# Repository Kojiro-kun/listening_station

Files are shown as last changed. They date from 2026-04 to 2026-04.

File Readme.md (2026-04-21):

# RF Listening Station

A high-performance radio receiver system based on the HackRF Pro, designed for stable, sensitive RF signal reception. This build combines precision clock synchronization, RF protection, and a portable form factor for reliable spectrum monitoring and analysis.

## Overview

This listening station delivers professional-grade performance through careful component selection and proper RF shielding. The core features include:

- **HackRF Pro** receiver for wideband signal reception (30 MHz - 6 GHz)
- **GPS-disciplined oscillator (GPSDO)** for frequency accuracy and stability
- **RF protection** via a limiter and attenuators for handling high-power signals
- **Battery-powered** operation for portable deployment
- **Compact mechanical design** using precision-machined discs and 3D-printed mounts

---

## Bill of Materials

### Radio Frequency Hardware

| Component | Part Number | Purpose |
|---|---|---|
| [HackRF Pro](https://greatscottgadgets.com/hackrf/pro/) | - | Wideband SDR receiver |
| [Mini-Circuits 6GHz Limiter](https://www.minicircuits.com/WebStore/dashboard.html?model=VLM-63-2W-S%2B) | VLM-63-2W-S+ | RF signal clipping & ESD protection |
| [Mini-Circuits DC to 6 GHz Attenuator](https://www.minicircuits.com/WebStore/dashboard.html?model=K1-VAT-A%2B) | K1-VAT-A+ | Input attenuation for high-power signals |
| [Double-shielded RG316D coax pigtail](https://www.ebay.com/itm/145242622653) | 10cm, SMA-M to SMA-M | Connects GPSDO to HackRF CLKIN |
| [Shielded M-F RG316 coax pigtail](https://www.amazon.com/dp/B091TH6CCJ?th=1) | 15cm, B091TH6CCJ | SMA bulkhead for the ground plane and HackRF |
| [SMA-M telescopic antenna](https://greatscottgadgets.com/ant500/) | ANT500 | Atatches to SMA bulkhead |

Also check out [Signal Stick SMA-M](https://signalstuff.com/products/st-sma-m/) antennas for easy access to HAM bands.

### Clock & Timing

| Component | Description |
|---|---|
| [Leo Bodnar LBE-1420 GPSDO](https://www.leobodnar.com/shop/index.php?main_page=product_info&products_id=393) | GPS-disciplined reference clock |
| [Leo Bodnar LBE-0006 Bracket](https://www.leobodnar.com/shop/index.php?main_page=product_info&products_id=402) | Mounting bracket for GPSDO |

### Power & USB

| Component | Specification | Purpose |
|---|---|---|
| [Bioenno Power Battery](https://www.bioennopower.com/products/12v-3ah-lifepo4-battery-pvc?_pos=2&_fid=890042680&_ss=c) | BLF-1203AB 12V 3Ah LiFePO4 | Clean DC power supply (8-10 hour runtime) |
| [DC Power Cable](https://www.amazon.com/dp/B0CW2MTHKS?th=1) | 5.5mm × 2.1mm male | Battery to hub connector |
| [StarTech USB C Hub](https://www.startech.com/en-us/usb-hubs/hb31c2a2cme) | 4-port, 10Gbps | Industrial low-EMI USB hub |
| [Digirig Shielded USB Cables](https://digirig.net/product/short-usb-a-to-usb-c-cable/) | Shielded and RF choked | High-quality USB 2.0 connectivity |

**Note:** You will need an Anderson Powerpole crimper and terminator kit to complete the DC power cable.

### Mechanical Components

#### Base Assembly (two discs, each 20cm radius)

| Component | Material & Spec | Purpose | Preview |
|---|---|---|---|
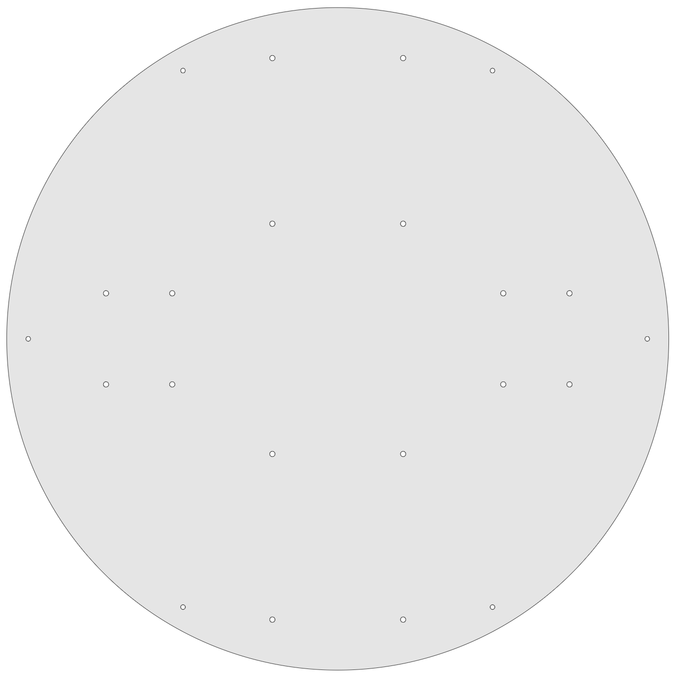
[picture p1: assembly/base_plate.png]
Base plate
| [Base plate](assembly/base_plate.dxf) | FR-4 G10 Black fiberglass, 0.125" | Primary mounting surface |  |
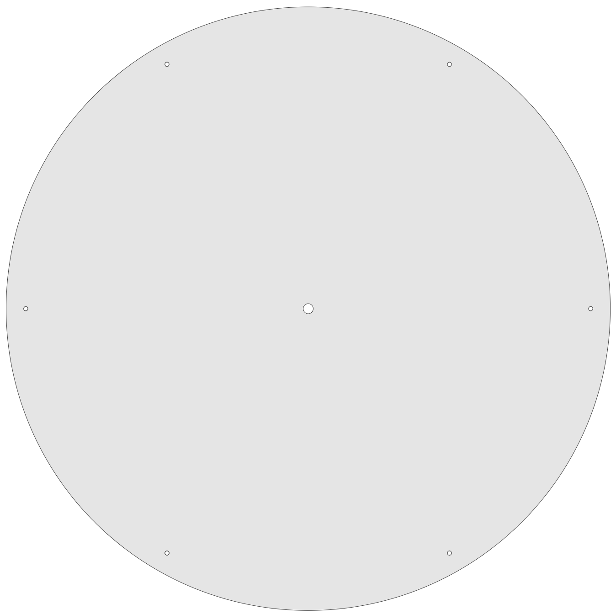
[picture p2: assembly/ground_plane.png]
Ground plane
| [Ground plane](assembly/ground_plane.dxf) | 5052 H32 Aluminum, 0.080" | RF shielding and counterpoise |  |

The linked manufacturing files  above are suitable for direct upload to [SendCutSend](https://sendcutsend.com/) or equivalent.

The base plate has mirrored through holes:
- North-South, for mounting the HackRF
- East-West, for mounting the GPSDO

License: [Creative Commons Attribution 4.0 International License](https://creativecommons.org/licenses/by/4.0/).

#### Fasteners & Mounts

| Type | Specification | Quantity | Application |
|---|---|---|---|
| M3-0.5 machine screws | 10mm | 4 | HackRF mounting brackets |
| M3-0.5 machine screws | 7mm | 4 | GPSDO mounting bracket |
| M3-0.5 Hex Nuts | DIN 439B thin | 8 | Secure machine screws for HackRF & GPSDO |
| M2.5-0.5 thumb screws | 8mm | 6 per disc (12 total) | Attach outer plate standoffs |
| M2.5-0.5 F-F standoffs | 20mm | 6 | Plate spacers |
| M2.5-0.5 M-F standoffs | 30mm | 6 | Plate spacers |

#### 3D Printed Parts

For the HackRF:
- [Mount, source](https://www.thingiverse.com/thing:3019950) (original design)
- [Mount, 1.0mm shorter](assembly/hackrf_mount_79mm_h-1.0.stl) (final design selection)
- [Mount, 1.5mm shorter](assembly/hackrf_mount_79mm_h-1.5.stl) (may also work)

The modified HackRF mount designs are all licensed under [CC4.0](https://creativecommons.org/licenses/by/4.0/).

Leo Bodnar has kindly given permission to host the [STEP file](assembly/0006%20wide%20mounting%20base.step) for the LBE-006 used in this project.
A tesselated STL variant, used for 3D printing, is available [here](assembly/0006%20wide%20mounting%20base.stl).

---

## Design Rationale

### Why LiFePO4 Battery Power?

- **Clean DC output with minimal ripple** - Essential for clock stability and receiver noise floor
- **AC noise isolation** - Wall adapters inject switching noise that degrades both the GPSDO accuracy and HackRF receiver performance
- **Portable operation** - 3Ah capacity provides 8-10 hours of continuous operation
- **Compact footprint** - Fits on the base plate without external enclosure

### Why RF Limiter?

- **30 MHz - 6 GHz coverage** with only 0.4 dB insertion loss
- **11.5 dB RF signal clamping** protects the HackRF frontend from damage
- **ESD protection** guards against static discharge during field use
- **Readily available** through DigiKey in the US

### Why Attenuators?

- **Dynamic range extension** - Allows safe reception of high-power signals that would exceed HackRF input limits
- **Prevents compression & damage** - Protects sensitive receiver stages
- **Configurable attenuation** - Adjust input levels based on signal environment
- **US availability** via DigiKey

### Why GPS-Disciplined Oscillator?

- **Frequency accuracy** - ±0.05 ppm from satellite references
- **Clock stability** - Essential for coherent signal analysis and tuning precision
- **Wideband receiver optimization** - Improves image rejection and phase noise characteristics

The HackRF Pro ships with a built-in TCXO that's decent for casual use, but it still drifts - typically a few ppm over temperature changes and time. At higher frequencies that drift gets multiplied: even 1 ppm of error at 1 GHz means you're off by 1 kHz, which is enough to smear a narrowband signal right out of your passband. For wideband scanning that might not matter much, but the moment you're trying to do anything precise - demodulating a narrowband FM signal, characterizing a filter's passband edges, or comparing signals across sessions - that drift becomes the limiting factor. The GPSDO locks the HackRF's sample clock to GPS-disciplined cesium references, pushing accuracy down to parts-per-billion and eliminating drift as a variable entirely. It turns the HackRF from a "good enough" receiver into a calibrated instrument.

To see the difference yourself, tune GQRX to a known stable signal - a local NOAA weather broadcast or an AM carrier works well. With the HackRF running on its internal oscillator, watch the waterfall over 15-20 minutes as the board warms up. You'll see the signal trace slowly wander left or right as the internal clock drifts, sometimes shifting by several hundred hertz. Now connect the GPSDO to CLKIN and restart GQRX. That same signal will pin to a single column in the waterfall and stay there indefinitely - no wander, no drift, just a rock-solid line. The visual difference is immediate and striking: a meandering smear versus a razor-sharp trace.

---

## Assembly

The base plate has two sets of mounting holes: outer M2.5 holes for the standoffs that support the ground plane, and inner M3 holes for mounting the electronics.

1. Insert the female bulkhead of an M-F RG316 coax into the center hole of the ground plane and tighten the mounting bolt using an adjustable wrench.
2. Position the HackRF over one of the N-S inner mounting areas, place the 3D-printed brackets over it, then secure using 4x M3×10mm machine screws and hex nuts.
3. Install the GPSDO mounting bracket using the corresponding E-W inner mounting holes with 4x M3×7mm machine screws, then insert the GPSDO.
4. Attach the USB hub to the plate between the remaining N-S inner HackRF mounting holes using Kapton tape.
5. Attach 6x M2.5 standoffs to the outer mounting holes of the base plate using M2.5 thumb screws (recommended total height: 50cm).
6. Attach an M-F RG316 coax to the HackRF's RF port.
7. Install the limiter between the HackRF's RF coax (step 6) and the ground plane bulkhead coax (step 1).
8. Connect the GPSDO to the HackRF's CLKIN port using an M-M 10cm RG316D coax, then connect the GPSDO's antenna.
9. Align the ground plane with the M2.5 standoffs and secure using 6x M2.5 thumb screws.

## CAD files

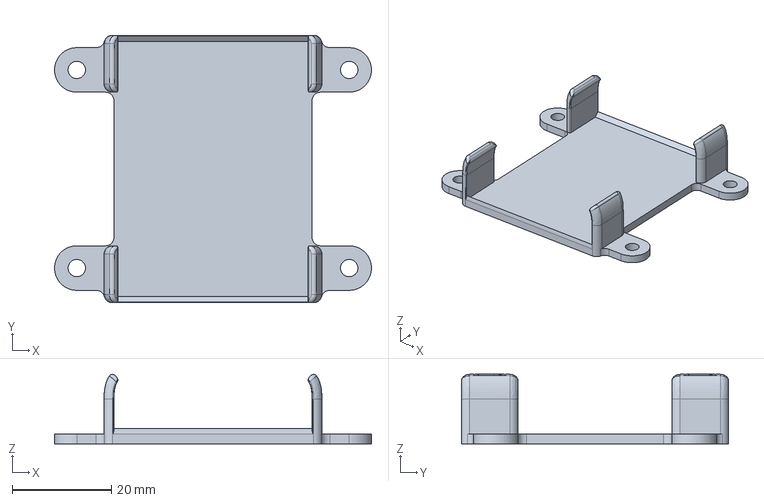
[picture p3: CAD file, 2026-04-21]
assembly/0006 wide mounting base.step
64.0 x 54.0 x 14.0 mm

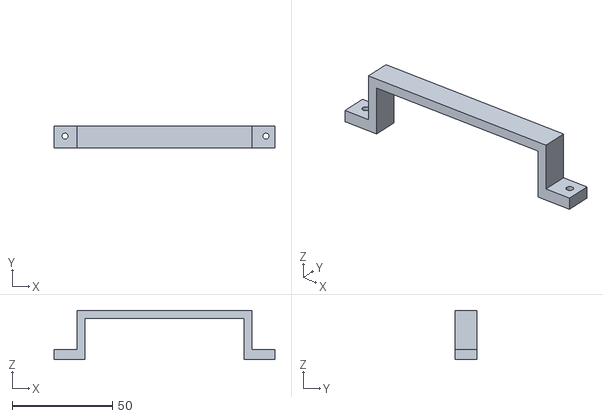
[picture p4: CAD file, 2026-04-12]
assembly/hackrf_mount_79mm_h-1.5.stl
110.0 x 11.0 x 24.5

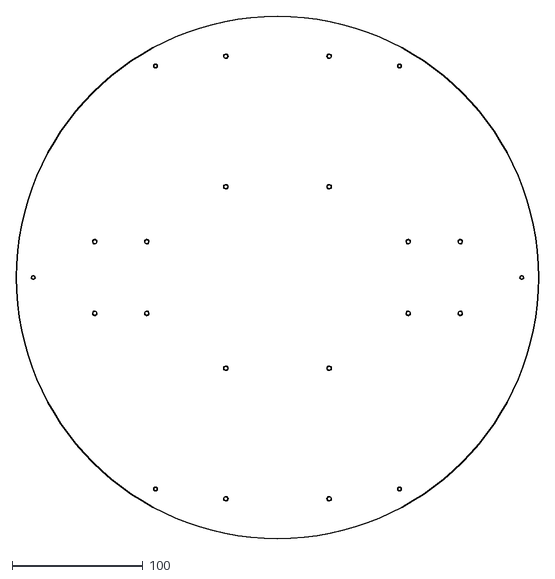
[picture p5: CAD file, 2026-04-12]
assembly/base_plate.dxf
400.0 x 400.0

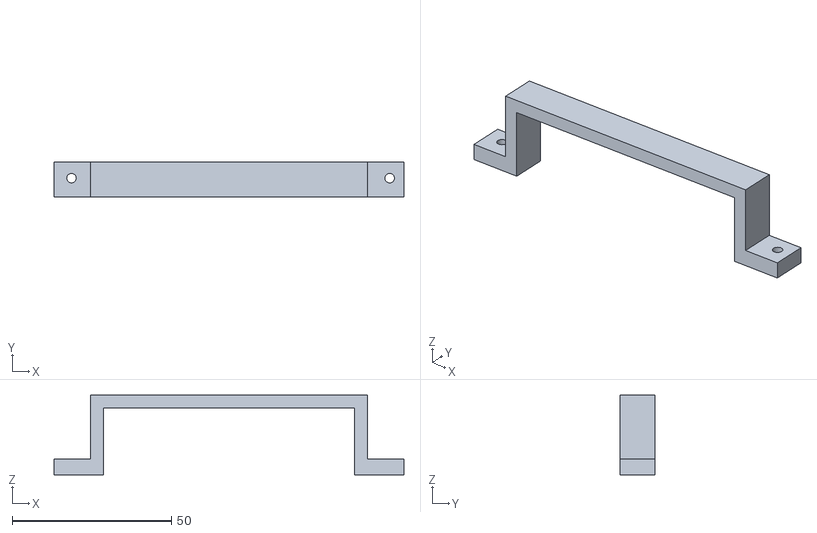
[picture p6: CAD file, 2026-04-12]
assembly/hackrf_mount_79mm_h-1.0.stl
110.0 x 11.0 x 25.0

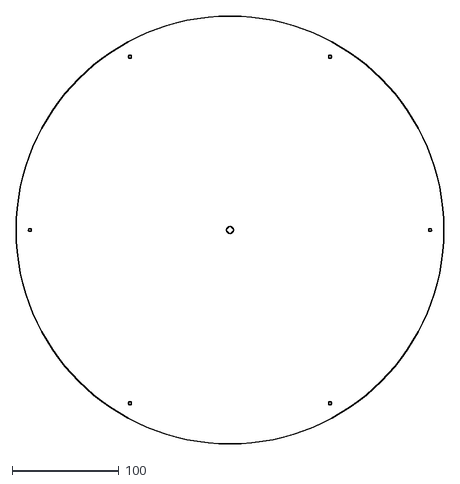
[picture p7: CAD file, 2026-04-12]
assembly/ground_plane.dxf
400.0 x 400.0

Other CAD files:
assembly/0006 wide mounting base.stl
